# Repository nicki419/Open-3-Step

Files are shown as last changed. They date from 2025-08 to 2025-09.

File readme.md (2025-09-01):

# Open 3 Step

Open-Source Circuit and code for custom built 120/240V 3-step (or  n-step) light bulb dimmer working by turning off/on the light switch  quickly to switch between brightness levels. Also provides  memory-functionality to non-memory 3-step bulbs.
Please take the time to read everything. It would mean a lot to me. Otherwise, just move on to docs/howto.md

---

### Background

I want to build a lamp. After making a beautiful frame for it, 3D-designing and printing bulb holders and other components, and buying designer LED bulbs (3 pairs of different bulbs, for a total of 6), I discovered that four of those bulbs were 3-step dimmable, and two were TRIAC dimmable. I therefore set out to make my TRIAC bulbs 3-step dimmable, with a memory function, so they could work with my 3-step bulbs.

I soldered a 5V power supply with some fuses, capacitors and resistors to a 30x70mm prototyping board, did the same for an ATMEGA328P, an EEPROM and some GPIO headers, wrote the arduino sketch (see v0.1 code) and it worked, after lots of debugging. If not for the next thing I discovered, this repository would not exist.

The dimming worked. The memory worked. Then it hit me. All four of my 3-step dimmable bulbs are from the same company, and have the exact same box design, with a myriad of icons on the side showing its features. Only after making v0.1 did I realise that two of the bulbs did NOT have a memory function, and two more did. So I now had four bulbs with memory, and two without. Since I also bought regular AC switch modules next to the RBDimmer module, I decided to make another version that would also control the two 3-step bulbs without memory.

Over the summer, I learned the basics of PCB Design and ordered my boards for the next version. I got some more components to make this project more easily customisable and added potentiometers for more easy brightness control at the three steps, as well as support for the non-memory 3-step bulbs.

### Versions

**0.2**

This version will implement the features described above on a custom PCB. All the components will, however, also fit on a 30x70mm prototyping board, if you really want to go that route.

To not clutter the repo, I will share exported PDFs, gerber files, STLs, etc. only via releases.

Changelog:

- Add Support for non-memory 3-step bulbs through fast switching when the system powers up
- Add analogue input via 100K potentiometers and a button to configure the brightness levels outside of code
- Move from arduino to platformio and add separate debug and release profiles (release will have no LED blinking)
- Create Settings Mode for configuring brightnesses and saving into EEPROM
- Create 3-step calibration mode to find out how long the delay in your bulbs is.

**0.1**

The original version is fully implementable on prototyping boards. This is also where the power supply comes from. I chose not to create schematics for the power supply, but there is documentation on what's required and recommended when creating it. If you only need 3-step dimming with a memory function, you may use the code from both v0.1 and v0.2. They should hopefully be cross-compatible, as the new board only adds things, it doesn't modify any existing pins. Consult the documentation of the v0.2 code once it fully releases on how to do this. During development, you probably want to use the v0.1 code, instead.

Therefore, you can refer to the schematics for v0.2 on how to wire everything. You simply need to leave out the push button, potentiometers, and the additional GPIO pin for the AC switch. You also need to configure the values for your bulb in code. For v0.2, I will place these in a header file, for v0.1, there is an array defined at the top of the code.

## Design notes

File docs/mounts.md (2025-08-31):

### 3D-Printed Mounts

I have included my 3D-printed mounts for all the PCBs in use in this repository. 
They include screwholes at the bottom to screw them into wood. 
I have done this because I will carve out parts of the wooden frame of my lamp to mount these.

They have been created in OpenSCAD, so it should be relatively easy to modify. 
If there's a release, you will find STL files in it. If not, just download openscad, open the files
and press F6 to render and F7 to export.

Files starting with an underscore are modules. They are only used in other files, you do not need to open these.

The RBDimmer module comes with an M2 version as well. That file also includes the washers needed to mount it with M2 screws.

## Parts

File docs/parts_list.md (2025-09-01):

# Parts List

This file covers the parts required for both v0.1, v0.2, and the power supply.

An asterisk denotes parts optional, but recommended. Links are non-affiliate AliExpress Links. I cannot guarantee that these will remain online, and I will not actively update them.

### General Purpose
These are "universal" parts you will need either way, so I will list them here. I will not add links because they are easy enough to find
- Solid Core Wire (both for soldering and connecting between terminal connectors
- GPIO Jumper Cables. Recommend you get Male to Male, Male to Female, and Female to Female. 
- Solder (duh)
- Flux/Rosin
- "Wire solder holder" (for lack of better description) Highly recommended because you'll likely solder gpio cables to thicker ones
  https://www.aliexpress.com/item/1005009535618361.html
- Stranded Wire rated for 240V 
- M2 and M3 Brass Screw inserts (M3 only needed for the RBDimmer. You can use M2 as well and use 3D-printed washers)

### V0.2 PCB
You have many options of ordering your PCB. I went with PCBWay because they offer IOSS (EU Vat prepaid) shipping methods, which is essential for delivery to where I live. Should you also choose PCBWay and have not ordered with them before, I would appreciate if you signed up using my referral link. You will get \$5 off on your first order, I get \$10 in coupons. That's all there's to it. [Click here <3](https://pcbway.com/g/Qr5ZNd)

### Power Supply

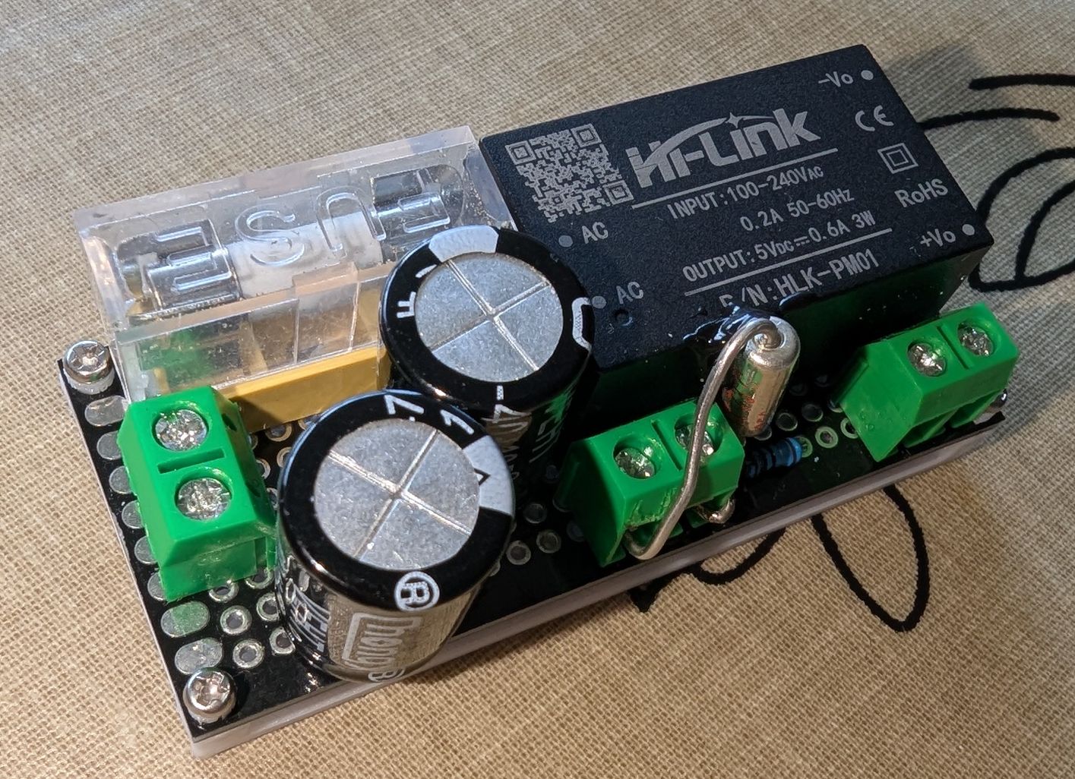
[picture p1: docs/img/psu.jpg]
Power Supply Unit


| Qty | Part | Link |
|---|---|---|
| 1 | 30x70mm Prototyping Board | https://www.aliexpress.com/item/1005009550650037.html |
| 1 | HLK-PM01 Power Supply Unit | https://www.aliexpress.com/item/1005007038304937.html |
| 2 (3*)<sup>1</sup> | KF301 2 Pin Terminal Connector | https://www.aliexpress.com/item/1005006642865467.html |
| 2 | 4700µF 10V Electrolytic Capacitors | https://www.aliexpress.com/item/1005008896677668.html |
| 1* | 5x20mm 250V 0.5A Slow-Blow Fuse | https://www.aliexpress.com/item/32871909497.html |
| 1* | 5x20mm Fuse Holder | https://www.aliexpress.com/item/1005005645173789.html |
| 1*<sup>1</sup> | 73° Thermal Fuse | https://www.aliexpress.com/item/1940867762.html |
| 1 | 10Ω Resistor | https://www.aliexpress.com/item/1005009329218922.html |

**Notes**

1. A third terminal connector I have used to mount the Thermal fuse. This is not good practice and you should probably use a connector made for these fuses.
   Do not make the same mistake as I and try to solder them. Turns out thermal fuses blow when they get hot. ;)

**Instructions**

- Fuses are in Series with the live line of your input. Their order should not matter, as the thermal fuse can handle 10A.
- Capacitors are in parallel with the HLK-PM01 output lines.
- The Resistor is in Series with the HLK-PM01's VCC output line before the caps. (I did it after, which is wrong. This resistor prevents current surge when charging capacitors, especially when adding more later)
- Use silicon rubber thermal glue to attach the thermal fuse to the HLK-PM01.

### v0.1
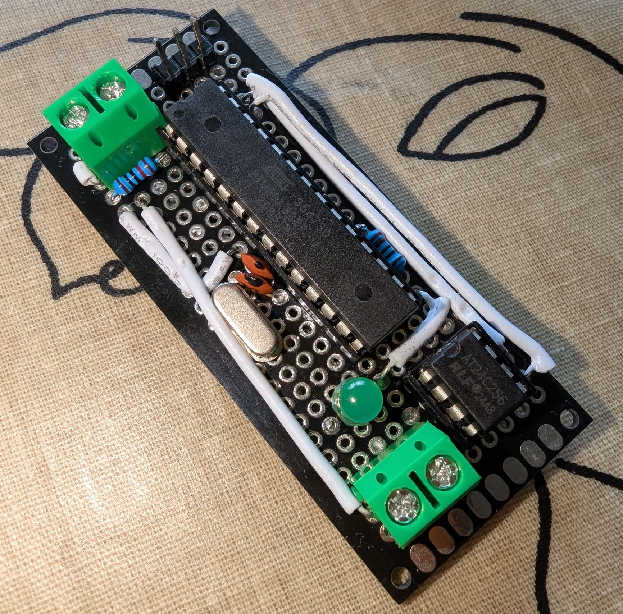
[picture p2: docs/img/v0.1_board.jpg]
V0.1 Board


| Qty | Part | Link |
|---|---|---|
| 1 | 30x70mm Prototyping Board | https://www.aliexpress.com/item/1005009550650037.html |
| 1 (2*)<sup>1</sup> | KF301 2 Pin Terminal Connector | https://www.aliexpress.com/item/1005006642865467.html |
| 1<sup>2</sup> | 16 MHz HC-49S Crystal Oscillator | https://www.aliexpress.com/item/1005005293770220.html |
| 2<sup>2</sup> | 30pF Ceramic Capacitor | https://www.aliexpress.com/item/1005007792464333.html |
| 1 | 5V LED | https://www.aliexpress.com/item/1005009402134026.html |
| 1 | 10KΩ Resistor | https://www.aliexpress.com/item/1005009329218922.html |
| 1 | 220Ω Resistor | https://www.aliexpress.com/item/1005009329218922.html |
| 2<sup>3</sup> | 4.7KΩ Resistor | https://www.aliexpress.com/item/1005009329218922.html |
| 1 | 28 Pin Narrow DIP Socket | https://www.aliexpress.com/item/1005006256010892.html |
| 1 | 8 Pin Narrow DIP Socket | https://www.aliexpress.com/item/1005006256010892.html |
| 1 | ATMEGA328P DIP | https://www.aliexpress.com/item/1005008144708950.html |
| 1 | AT24C256 DIP | https://www.aliexpress.com/item/1005006779000585.html |
| 1<sup>4</sup> | 1x3 pin Male GPIO Headers | https://www.aliexpress.com/item/1005003323489438.html |

**Notes**
1. You only need one for input. But I recommend one at the other side of the board for output to the components that have their own PCB.
2. I recommend you find a listing that specifies the load capacitance, like the one I linked. You can then calculate the exact capacitor values needed for your load capacitors.
   Formula: C = 2 × (CL - Cstray) where CL is the load capacitance, and Cstray is the stray capacitance (typically 5pF)
3. My original v0.1 board did not have these, and it worked, but that turned out to be dumb luck. I highly recommend you add them.
   Needed for I2C communication between the ATMEGA328P and the AT24C256.
4. Buy any size, unlike the female ones, these are easy to cut.

### v0.2

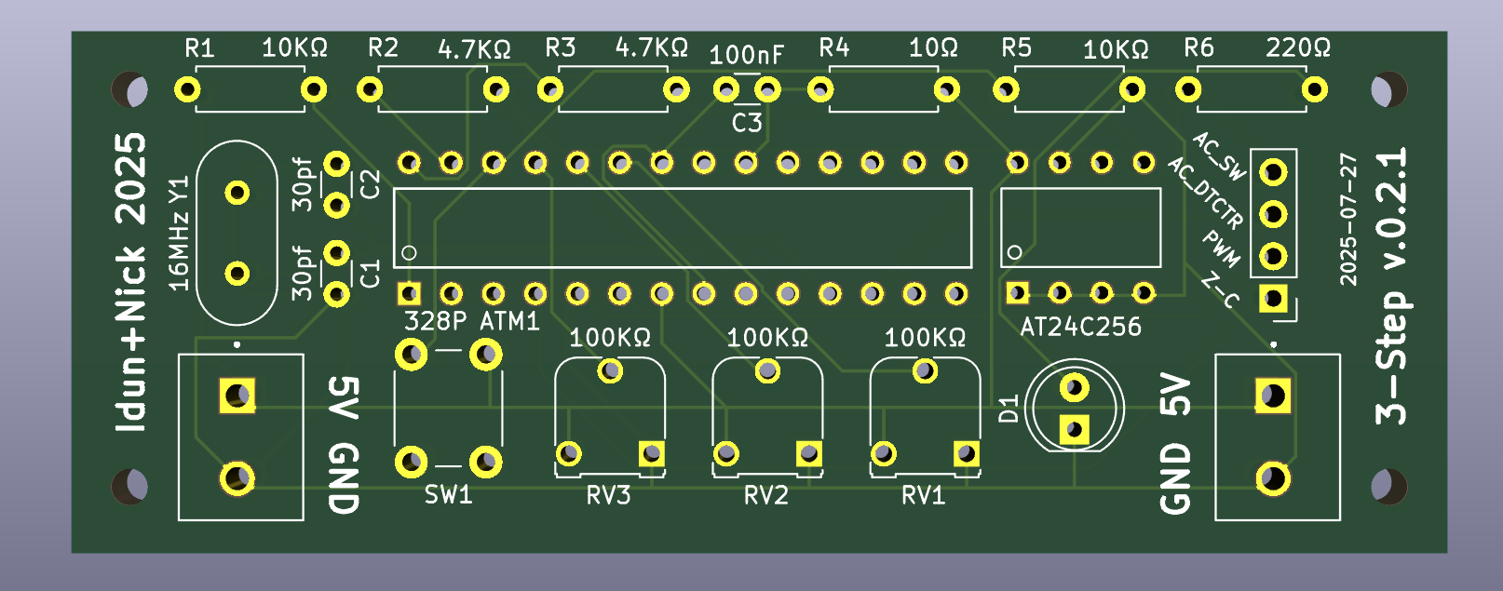
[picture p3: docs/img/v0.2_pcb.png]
V0.2 PCB


| Qty | Part | Link |
|---|---|---|
| 1 | PCB from Repo | [My PCBWay Referral Link](https://pcbway.com/g/Qr5ZNd) |
| 2 | KF301 2 Pin Terminal Connector | https://www.aliexpress.com/item/1005006642865467.html  |
| 1<sup>1</sup> | 16 MHz HC-49S Crystal Oscillator | https://www.aliexpress.com/item/1005005293770220.html  |
| 2<sup>1</sup> | 30pF Ceramic Capacitor | https://www.aliexpress.com/item/1005007792464333.html  |
| 1 | 100nF Ceramic Capacitor | https://www.aliexpress.com/item/1005007792464333.html  |
| 1 | 5V LED | https://www.aliexpress.com/item/1005009402134026.html  |
| 2 | 10KΩ Resistor | https://www.aliexpress.com/item/1005009329218922.html  |
| 1 | 220Ω Resistor | https://www.aliexpress.com/item/1005009329218922.html  |
| 2 | 4.7KΩ Resistor | https://www.aliexpress.com/item/1005009329218922.html  |
| 1 | 10Ω Resistor | https://www.aliexpress.com/item/1005009329218922.html  |
| 1 | 28 Pin Narrow DIP Socket | https://www.aliexpress.com/item/1005006256010892.html  |
| 1 | 8 Pin Narrow DIP Socket | https://www.aliexpress.com/item/1005006256010892.html  |
| 1 | ATMEGA328P DIP | https://www.aliexpress.com/item/1005008144708950.html  |
| 1 | AT24C256 DIP | https://www.aliexpress.com/item/1005006779000585.html  |
| 1<sup>2</sup> | 1x4 pin Male GPIO Headers | https://www.aliexpress.com/item/1005003323489438.html  |
| 1 | 6x6mm TS-D001 Tactile Switch | https://www.aliexpress.com/item/1005004159746274.html  |
| 3 | RM065 100KΩ Potentiometers | https://www.aliexpress.com/item/1005003523757457.html  |

**Notes**
1. See v0.1 Note 2
2. See v0.1 Note 4

### Other
These are the standalone PCBs. Including Pictures I took in case the links are down.

**Robotdyn RBDimmer Module** https://www.aliexpress.com/item/1005008561862601.html
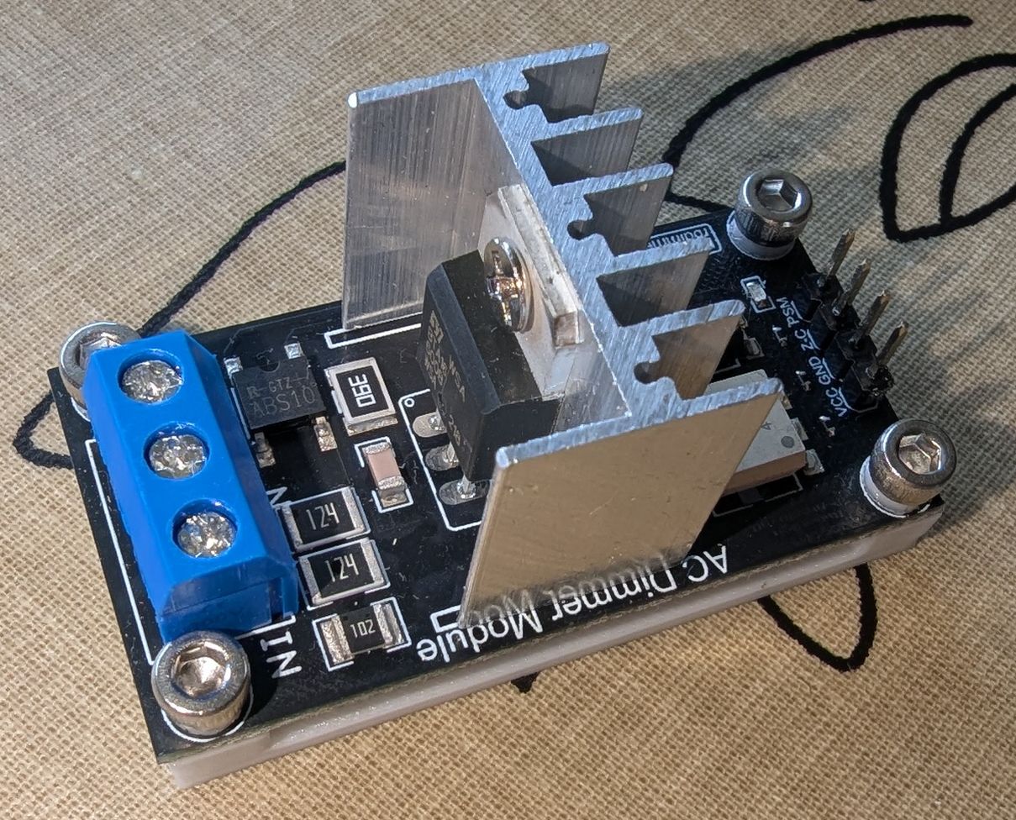
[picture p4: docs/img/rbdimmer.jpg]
RBDimmer Image


**AC Switch (JQC3F-05VDC-C with Control Board (5V)) (v0.2 only, optional)** https://www.aliexpress.com/item/1005004594181635.html

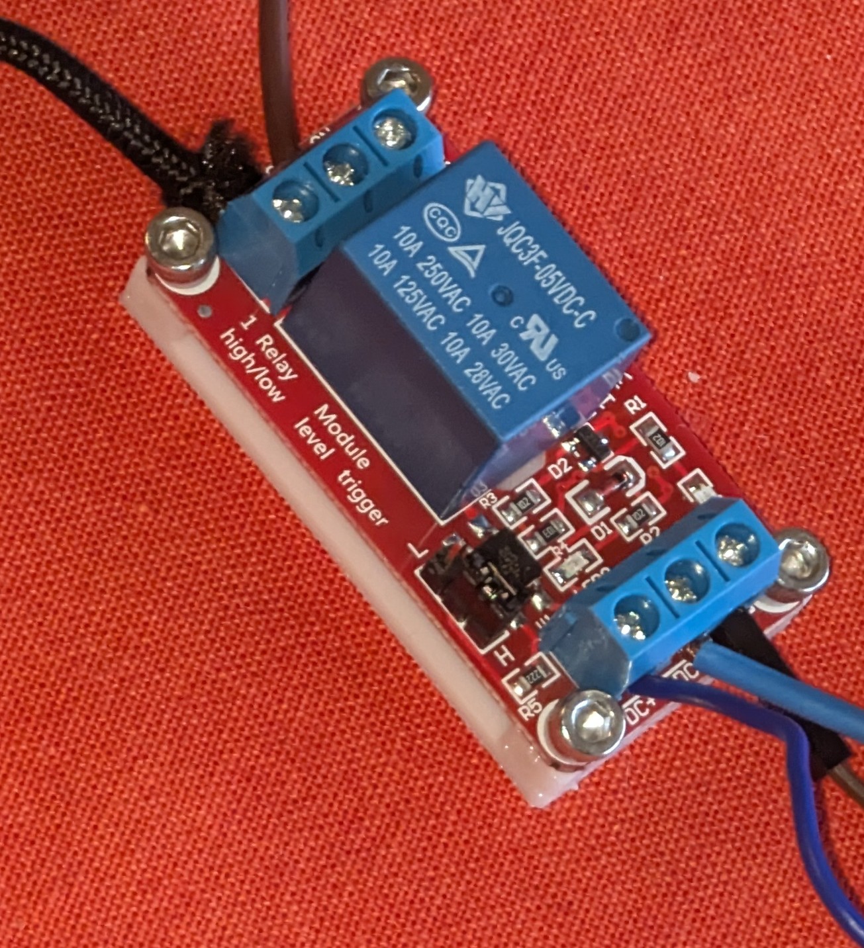
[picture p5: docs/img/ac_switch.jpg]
AC Switch Image


**AC Detector Module 3.3/5V** https://www.aliexpress.com/item/1005005829148627.html
You might ask yourself why we need this. _Can't we just detect the output the the HLK-PM01?_ That Power suppy unit has inbuilt capacitors. It would take a good second after turning off the AC supply for the voltage to drop to 0. This board detects the absence of AC voltage immediately.
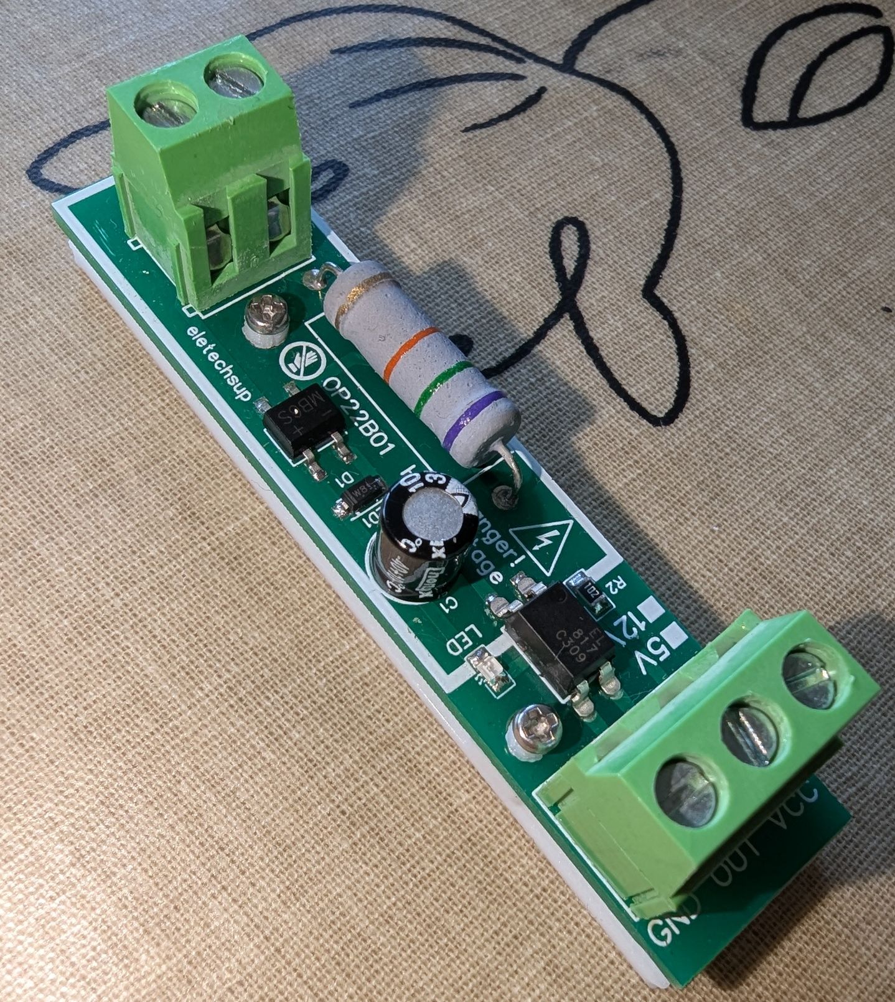
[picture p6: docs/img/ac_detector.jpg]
AC Detector Image


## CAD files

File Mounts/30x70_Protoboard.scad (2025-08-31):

$fn = $preview ? 0 : 100;

include <_modules.scad>;
include <_generic_board.scad>;

length = 70;
width = 30;
height = 2;

mounting_hole_length = 4;
mounting_hole_width = 4;
mounting_hole_height = 4;

screw_hole_x = 15;
screw_hole_y = 15;

difference()
{
    generic_board(length, width, height, mounting_hole_length, mounting_hole_width, mounting_hole_height);
    union()
    {
        translate([screw_hole_x, screw_hole_y, 0])
        wood_hole();
        
        translate([length - screw_hole_x, screw_hole_y, 0])
        wood_hole();
    }
}

translate([(3-3/4), width + 5, 0])
for(i = [0 : 1])
{
    for(j = [0 : 1])
    {
        translate([i*5, j*5, 0]) washer();
        translate([i*5, j*5, 0]) washer();
    }
}

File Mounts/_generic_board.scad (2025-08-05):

module generic_board_m3(
length,
width,
height,
mounting_hole_length,
mounting_hole_width,
mounting_hole_height = 3
)
{
    cube([length, width, height]);

    translate([mounting_hole_length / 2, mounting_hole_width / 2, height])
    mounting_hole_m3(mounting_hole_length, mounting_hole_width, mounting_hole_height);

    translate([mounting_hole_length / 2, width - (mounting_hole_width / 2), height])
    mounting_hole_m3(mounting_hole_length, mounting_hole_width, mounting_hole_height);

    translate([length - (mounting_hole_length / 2), mounting_hole_width / 2, height])
    mounting_hole_m3(mounting_hole_length, mounting_hole_width, mounting_hole_height);

    translate([length - (mounting_hole_length / 2), width - (mounting_hole_width / 2), height])
    mounting_hole_m3(mounting_hole_length, mounting_hole_width, mounting_hole_height);
}

module generic_board(
length,
width,
height,
mounting_hole_length,
mounting_hole_width,
mounting_hole_height = 3
)
{
    cube([length, width, height]);

    translate([mounting_hole_length / 2, mounting_hole_width / 2, height])
    mounting_hole(mounting_hole_length, mounting_hole_width, mounting_hole_height);

    translate([mounting_hole_length / 2, width - (mounting_hole_width / 2), height])
    mounting_hole(mounting_hole_length, mounting_hole_width, mounting_hole_height);

    translate([length - (mounting_hole_length / 2), mounting_hole_width / 2, height])
    mounting_hole(mounting_hole_length, mounting_hole_width, mounting_hole_height);

    translate([length - (mounting_hole_length / 2), width - (mounting_hole_width / 2), height])
    mounting_hole(mounting_hole_length, mounting_hole_width, mounting_hole_height);
}

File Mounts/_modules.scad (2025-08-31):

module mounting_hole(w, l, h=3) 
{
    hole_dia = 3.0;           // slightly undersized for 3.2mm insert
    hole_depth = 2.2;         // slightly deeper than insert
    chamfer_depth = 0.5;      // how deep the chamfer is
    chamfer_top_dia = 3.4;    // wider top to guide insert

    // Create the main hole and chamfer at the top
    difference() 
    {
        translate([-(w/2),-(l/2),0])
        {
            cube([w,l,h]);
        }
        translate([0,0,3+(h-3)+.01]) 
        {
            rotate([180,0,0]) 
            {
                union() {
                    // Main cylindrical hole
                    cylinder(d = hole_dia, h = hole_depth, $fn = 64);

                    // Top chamfered cone
                    cylinder(d1 = chamfer_top_dia, d2 = hole_dia, h = chamfer_depth, $fn = 64);
                }
            }
        }
    }
}

module mounting_hole_m3(w, l, h=3) 
{
    hole_dia = 4.2;           // slightly undersized for 3.2mm insert
    hole_depth = 3;         // slightly deeper than insert
    chamfer_depth = 0.5;      // how deep the chamfer is
    chamfer_top_dia = 4.8;    // wider top to guide insert

    // Create the main hole and chamfer at the top
    difference() 
    {
        translate([-(w/2),-(l/2),0])
        {
            cube([w,l,h]);
        }
        translate([0,0,3+(h-3)+.01]) 
        {
            rotate([180,0,0]) 
            {
                union() {
                    // Main cylindrical hole
                    cylinder(d = hole_dia, h = hole_depth, $fn = 64);

                    // Top chamfered cone
                    cylinder(d1 = chamfer_top_dia, d2 = hole_dia, h = chamfer_depth, $fn = 64);
                }
            }
        }
    }
}

module wood_hole()
{
    hole_dia = 3;
    head_dia = 6;
    hole_depth = 3;
    
    translate([0,0,2.01]) 
    {
        rotate([180,0,0]) 
        union() {
            // Main cylindrical hole
            cylinder(d = hole_dia, h = hole_depth, $fn = 64);

            // Top chamfered cone
            cylinder(d1 = head_dia, d2 = hole_dia, h = 1.25, $fn = 64);
        }
    }
}

module washer(size = 2)
{
    difference()
    {
        cylinder(r=size-size/4, h=1.5);
        cylinder(r=size/2, h=1.5);
    }
}

module washer_m2_to_m3()
{
    difference()
    {
        cylinder(r=3-3/4, h=1.5);
        cylinder(r=1, h=1.5);
    }
}

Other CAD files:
Mounts/AC_Detector.scad
Mounts/AC_Dimmer.scad
Mounts/AC_Dimmer_M2.scad
Mounts/AC_Switch.scad
Mounts/AC_Switch_M2.scad
Mounts/Main_PCB.scad

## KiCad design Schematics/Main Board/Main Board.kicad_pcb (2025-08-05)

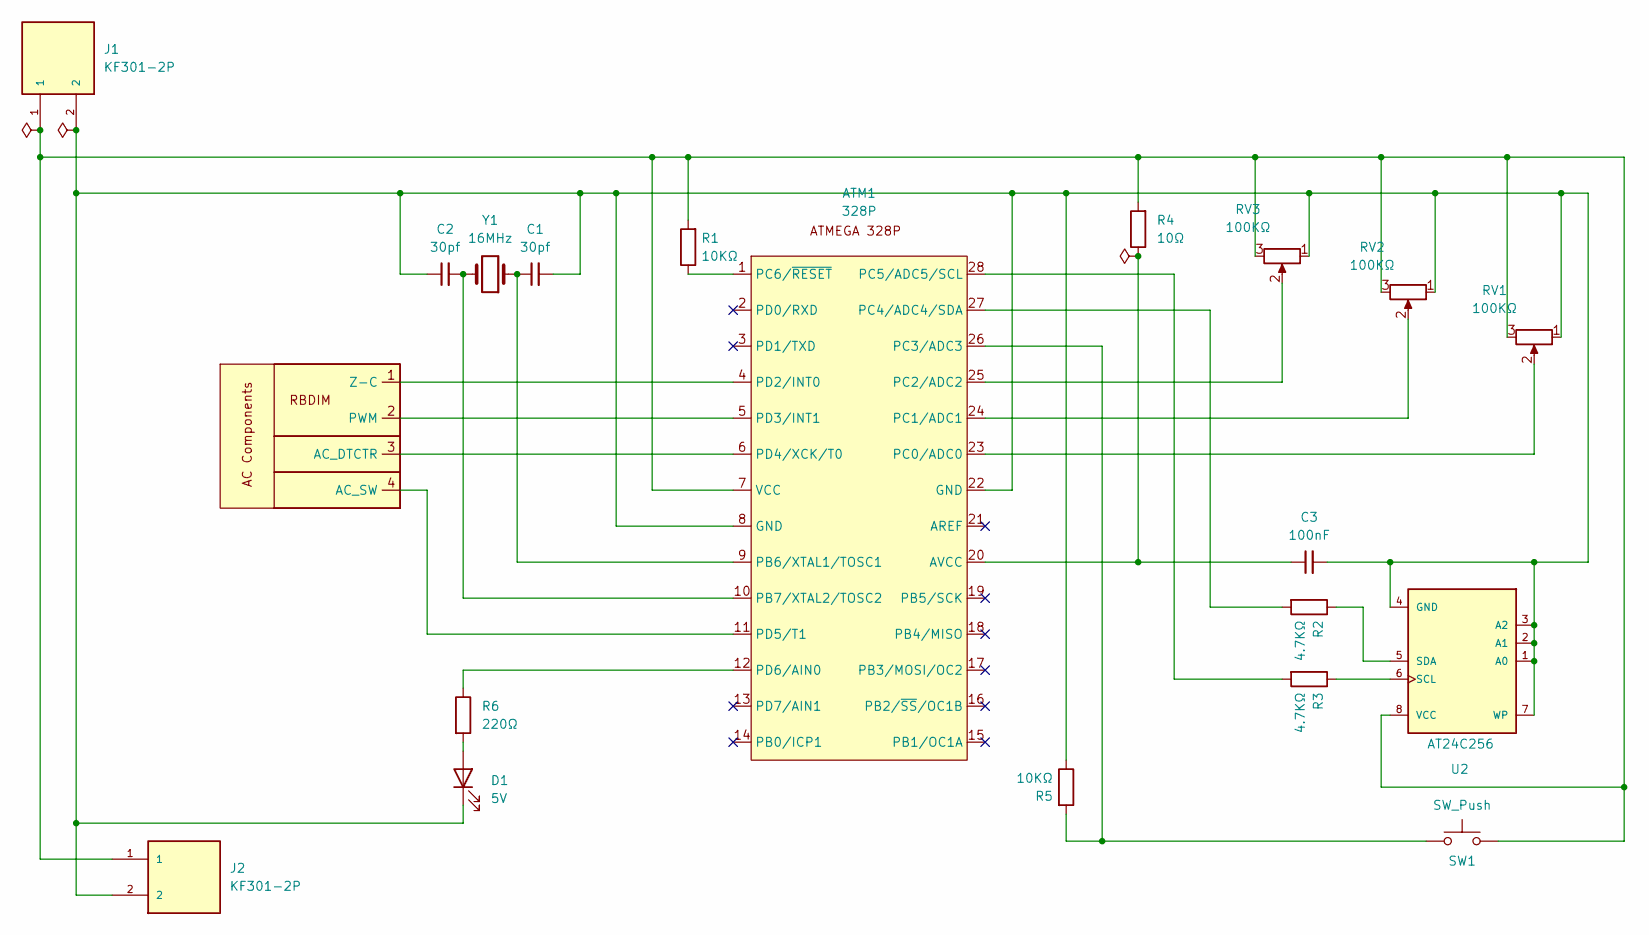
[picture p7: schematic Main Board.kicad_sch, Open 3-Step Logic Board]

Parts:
ATM1: 328P; DIP794W46P254L2967H457Q28B
C1, C2: 30pf; C_Disc_D3.0mm_W1.6mm_P2.50mm
C3: 100nF; C_Disc_D3.0mm_W1.6mm_P2.50mm
D1: 5V; LED_D5.0mm
J1, J2: KF301-2P; HANDSON_KF301-2P; PARTREV NA
R1, R5: 10KΩ; R_Axial_DIN0207_L6.3mm_D2.5mm_P7.62mm_Horizontal
R2, R3: 4.7KΩ; R_Axial_DIN0207_L6.3mm_D2.5mm_P7.62mm_Horizontal
R4: 10Ω; R_Axial_DIN0207_L6.3mm_D2.5mm_P7.62mm_Horizontal
R6: 220Ω; R_Axial_DIN0207_L6.3mm_D2.5mm_P7.62mm_Horizontal
RV1, RV2, RV3: 100KΩ; Potentiometer_Runtron_RM-065_Vertical
SW1: SW_Push; SW_PUSH_6mm_H5mm
U1: PinHeader_1x04_P2.54mm_Vertical
U2: AT24C256; DIP787W46P254L927H533Q8
Y1: 16MHz; Crystal_HC49-U_Vertical

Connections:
unnamed: ATM1.20 (AVCC), C3.1, R4.1
unnamed: ATM1.9 (PB6/XTAL1/TOSC1), C1.1, Y1.1
unnamed: ATM1.10 (PB7/XTAL2/TOSC2), C2.2, Y1.2
unnamed: ATM1.23 (PC0/ADC0), RV1.2
unnamed: ATM1.24 (PC1/ADC1), RV2.2
unnamed: ATM1.25 (PC2/ADC2), RV3.2
unnamed: ATM1.26 (PC3/ADC3), R5.2, SW1.1
unnamed: ATM1.27 (PC4/ADC4/SDA), R2.2
unnamed: ATM1.28 (PC5/ADC5/SCL), R3.2
unnamed: ATM1.1 (PC6/~RESET), R1.1
unnamed: ATM1.4 (PD2/INT0), U1.1 (Z-C)
unnamed: ATM1.5 (PD3/INT1), U1.2 (PWM)
unnamed: ATM1.6 (PD4/XCK/T0), U1.3 (AC_DTCTR)
unnamed: ATM1.11 (PD5/T1), U1.4 (AC_SW)
unnamed: ATM1.12 (PD6/AIN0), R6.1
unnamed: ATM1.7 (VCC), J1.1, J2.1, R1.2, R4.2, RV1.3, RV2.3, RV3.3, SW1.2, U2.8 (VCC)
unnamed: D1.2 (A), R6.2
unnamed: ATM1.8 (GND), ATM1.22 (GND), C1.2, C2.1, C3.2, D1.1 (K), J1.2, J2.2, R5.1, RV1.1, RV2.1, RV3.1, U2.1 (A0), U2.2 (A1), U2.3 (A2), U2.4 (GND), U2.7 (WP)
unnamed: R3.1, U2.6 (SCL)
unnamed: R2.1, U2.5 (SDA)

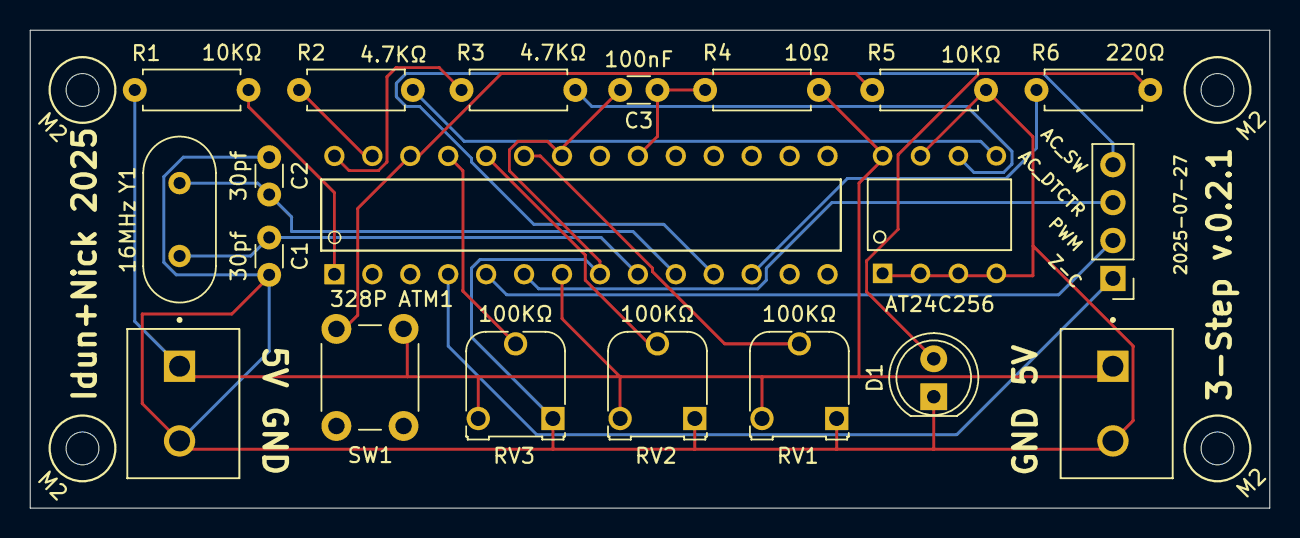
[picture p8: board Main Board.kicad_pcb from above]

Board: 2 copper layers, 83.0 x 32.0 mm, 20 parts (0 on the bottom side), 20 nets.

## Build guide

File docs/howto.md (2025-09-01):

# How To Install and Setup the Dimmer

1. Download the latest release. It contains STL files for mounts, schematics pdf and gerber files for the PCB, and compiled debug and release firmware for delays of 100ms to 5000ms (explained later)
2. Read through mounts.md and parts_list.md. Order the PCB if you don't want to solder on a protoboard (highly recommended)
3. Solder all components, prepare the boards, wire everything up.
4. Load the debug 5000ms firmware onto your 328P, and "boot" the system.
5. The lamp will either be on full brightness, or off. This is normal.

## Setting up the brightness levels

First things first - you need to decide in what order you want to dim. It can either be HIGH - MEDIUM - LOW or LOW - MEDIUM - HIGH. If you use this system, like me, with another 3-step dimmable lamp, whether that has a memory or not, you need to use the order it uses.

To enter settings mode, double click the button. Your lamp will now assume the brightness the first potentiometer is set to. You can turn the potentiometer, then click the button once. That will show you the new brightness, and also save it to the EEPROM. When setting the lowest brightness, some TRIAC dimmable bulbs have a minimum they can handle on boot, which might be higher than the minimum you can set it to. Mine, for instance, when at its absolute lowest can not turn on from a state of prolonged off-time to it's lowest possible brightness, so I had to configure it to be some 10% brighter than it's theoretical lowest.

Double tap again to exit settings mode. The step you were currently on is the step that will be used. Hence, the settings mode also serves to toggle through the three steps, to sync it up with your 3-step bulbs with their own memory.

## Measuring the delay of your 3-step bulbs

When using this together with regular 3-step bulbs, you'll want to know their max switching delay. You need to match the firmware you use for that delay, hence the release contains delays from 100ms to 5000ms. When not in settings mode, hold the button to enter the calibration mode.

Two important things to note: While calibrating, do not rest your finger on the button. That might trigger a button hold and leave calibration mode. You will also need your phone to be able to record timelapse at 1/2, ideally 1/4 so you can count easier. When testing with a bulb that does not have its own memory, take not of its default state. You DO NOT want to test when on the state before that, because you would not be able to tell it apart.
For example, my bulb defaults to HIGH. I therefore made sure when testing delays it was on MEDIUM. In case the delay tested does trigger it, it would switch to LOW. In case it did not, it would switch to HIGH. That's how I knew I'd foudn my delay. In my bulb, it stopped switching at 4100ms, so my max delay is 4000 ms.

Press the button to toggle at the current delay. It starts at 100ms. The LED will be ON once for every 100ms of delay. Double click the button to increase the delay by 100ms. Do not bother counting. Just keep increasing and testing until you've found the FIRST delay where your lamp no longer switches. Press the button once to repeat that delay, and record the LED with your phone in slow motion. You can then count how often it blinks easily, subtract 100ms, and you'll know your delay.

## The issue of uptime

Capacitors degrade over time. Up to 30% can be expected. I therefore recommend you add, on another protoboard, as many capacitors as necessary according to the following (crude) calculation:

(Your delay + 500ms)*1.3

That will give you your required uptime. Add enough capacitors to reach it. I found each cap adds roughly 500ms, but that'S based on very crude measurements. I consider the system dead as soon as the LED dies, because it's driven by the 328P. I therefore assume as long as the LED is on, the system is live.

Test on a breadboard how many caps you need, add one for good measure, and you're hopefully good to go.

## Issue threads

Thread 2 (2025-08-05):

M3 Washer with M2 Hole for RBDimmer

nicki419, 2025-08-05:
Some People might not want to buy two separate sizes of brass inserts and screws.

- Create a washer covering the M3 hole that will allow users to use M2 screws and brass inserts for the RBDimmer

Closed 2025-08-05.

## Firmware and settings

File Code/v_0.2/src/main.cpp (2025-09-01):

#include <RBDdimmer.h>
#include <Wire.h>
#include <at24c256.h>
#include <Arduino.h>
#include <IO_Pins.h>
#include <brightness_controller.h>
#include <Storage_Addresses.h>
#include <OneButtonTiny.h>

#include "ac_switch_controller.h"
#include "settings_controller.h"
#include "delay.h"

#define AC_SW_DELAY 75

constexpr int brightnessLevels[3] = {30, 60, 100}; // brightness % levels

dimmerLamp dimmer(DIMMER_PIN);
AT24C256* eeprom = nullptr;
BrightnessController* brightnessController = nullptr;
SettingsController* settingsController = nullptr;
ACSwitchController* acSwitchController = nullptr;
OneButtonTiny* button = nullptr;

unsigned long mainsLostTime = 0;
bool mainsPresent = true;
unsigned long lastBlinkTime = 0;
bool ledOn = false;
bool inSettingsLoop = false;
bool inACSwitchLoop = false;

void loadBrightness() {
  const int currentBrightnessIndex = brightnessController->readWithRetry(BRIGHTNESS_INDEX_ADDR, 2);
  brightnessController->setCurrentBrightnessIndex(currentBrightnessIndex);
}

void handleClick() {

}

void handleHold() {

}

void setup() {
  pinMode(MAINS_DETECT_PIN, INPUT);
  pinMode(STATUS_LED_PIN, OUTPUT);
  pinMode(BUTTON_PIN, INPUT);
  pinMode(POT1_PIN, INPUT);
  pinMode(POT2_PIN, INPUT);
  pinMode(POT3_PIN, INPUT);
  pinMode(AC_SW_PIN, OUTPUT);

  Wire.begin();
  dimmer.begin(NORMAL_MODE, ON);
  eeprom = new AT24C256(0x50, Wire);
  brightnessController = new BrightnessController(&dimmer, eeprom);
  button = new OneButtonTiny(
        BUTTON_PIN,
        false,
        false
    );
  settingsController = new SettingsController(&dimmer, eeprom, brightnessController, button);
  acSwitchController = new ACSwitchController(&dimmer, eeprom, brightnessController, button);

  loadBrightness();
  brightnessController->applyBrightness();
  acSwitchController->handleACSwitch(AC_SW_DELAY);

#ifdef DEBUG
  digitalWrite(STATUS_LED_PIN, HIGH);
  delay(50);
  digitalWrite(STATUS_LED_PIN, LOW);
#endif

  button->attachClick([]() {
    if (!inSettingsLoop && !inACSwitchLoop) {
      handleClick();
    }
    else if (inSettingsLoop) {
      settingsController->handle_button_click(brightnessController->getCurrentBrightnessIndex());
    }
    else if (inACSwitchLoop) {
      acSwitchController->handle_button_click();
    }
  });

  button->attachDoubleClick([]() {
    digitalWrite(STATUS_LED_PIN, HIGH);
    delay(100);
    digitalWrite(STATUS_LED_PIN, LOW);
    delay(100);

    if (!inACSwitchLoop) {
      inSettingsLoop = !inSettingsLoop;
      if (inSettingsLoop) {
        brightnessController->setCurrentBrightnessIndex(0);
        settingsController->handle_button_click(brightnessController->getCurrentBrightnessIndex());
      }
    }
    else {
      acSwitchController->handle_button_double_click();
    }
  });

  button->attachLongPressStart([]() {
    if (!inSettingsLoop) {
      inACSwitchLoop = !inACSwitchLoop;
      if (inACSwitchLoop) {
        acSwitchController->currentTestIndex = 1;
        digitalWrite(STATUS_LED_PIN, LOW);
        delay(200);
      }
    }
    else {
      settingsController->handle_button_hold(brightnessController->getCurrentBrightnessIndex());
    }
  });

}

void loop() {
  button->tick();
  const bool currentMains = (digitalRead(MAINS_DETECT_PIN) == LOW);

  if (inSettingsLoop) {
    settingsController->settings_loop(brightnessController->getCurrentBrightnessIndex());
    return;
  }
  if (inACSwitchLoop) {
    return;
  }

  // Mains Power Cycle Check
  if (!mainsPresent && currentMains) {
    if (const unsigned long interruption = millis() - mainsLostTime; interruption <= DELAY) {
      brightnessController->cycleBrightness();
      const int currentBrightnessIndex = brightnessController->getCurrentBrightnessIndex();
      brightnessController->applyBrightness();
      brightnessController->saveBrightnessIndex(currentBrightnessIndex);
    }
    else {
      acSwitchController->handleACSwitch(AC_SW_DELAY);
    }
  }

  if (mainsPresent && !currentMains) {
    mainsLostTime = millis();
  }

  mainsPresent = currentMains;
  brightnessController->handleStatusLED();

  delay(10);
}

void onZeroCross() {
  dimmer.setState(ON);
}

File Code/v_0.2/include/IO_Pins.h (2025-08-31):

//
// Created by nick on 05/08/25.
//

#ifndef IO_PINS_H
#define IO_PINS_H

#define MAINS_DETECT_PIN PD4     // Mains detector output (LOW = mains present)
#define ZERO_CROSS_PIN PD2       // Zero-cross input for dimmer timing
#define DIMMER_PIN PD3           // Dimmer PSM output
#define STATUS_LED_PIN PD6       // External status LED
#define AC_SW_PIN PD5            // AC switch output

#define POT1_PIN A0             // ADC2 (PC2/A2)
#define POT2_PIN A1             // ADC1 (PC1/A1)
#define POT3_PIN A2             // ADC0 (PC0/A0)
#define BUTTON_PIN A3           // ADC3 (PC3/A3) Used as digital input

#endif //IO_PINS_H

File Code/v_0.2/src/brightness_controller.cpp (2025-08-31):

#include <brightness_controller.h>
#include <RBDdimmer.h>
#include <Arduino.h>
#include <at24c256.h>
#include <Storage_Addresses.h>

#ifdef DEBUG
#include <IO_Pins.h>
#endif

BrightnessController::BrightnessController(dimmerLamp* dimmer, AT24C256* eeprom) : dimmer(dimmer), eeprom(eeprom) {

}

bool BrightnessController::writeAndVerify(const byte address, const byte data) const {
    dimmer->setPower(0);
    dimmer->setState(OFF);
    delay(50);
    for (int attempt = 0; attempt < 3; attempt++) {
        eeprom->write(address, data);
        delay(20);

        if (const byte readBack = eeprom->read(address); readBack == data) {
            dimmer->setState(ON);
            applyBrightness();
            return true;
        }
    }

    dimmer->setState(ON);
    applyBrightness();
    return false;
}

byte BrightnessController::readWithRetry(const byte address, const byte defaultValue) const {
    for (int attempt = 0; attempt < 3; attempt++) {
        dimmer->setPower(0);
        dimmer->setState(OFF);
        delayMicroseconds(100);

        if (const byte value = eeprom->read(address); value < 3) {
            dimmer->setState(ON);
            return value;
        }
    }

    dimmer->setState(ON);
    return defaultValue;
}

byte BrightnessController::readBrightnessWithRetry(const byte address, const byte defaultValue) const {
    for (int attempt = 0; attempt < 3; attempt++) {
        dimmer->setPower(0);
        dimmer->setState(OFF);
        delayMicroseconds(100);

        if (const byte value = eeprom->read(address); value >= 1 && value <= 100) {
            dimmer->setState(ON);
            return value;
        }
    }
    dimmer->setState(ON);
    return defaultValue;
}


void BrightnessController::saveBrightnessIndex(const int currentBrightnessIndex) const {
    if (!writeAndVerify(BRIGHTNESS_INDEX_ADDR, currentBrightnessIndex)) {
        // Write failed - indicate error by rapid LED flashing
#ifdef DEBUG
        for (int i = 0; i < 5; i++) {
            digitalWrite(STATUS_LED_PIN, HIGH);
            delay(50);
            digitalWrite(STATUS_LED_PIN, LOW);
            delay(50);
        }
#endif
    }
}

void BrightnessController::applyBrightness() const {
    const int address = currentBrightnessIndex == 0
                            ? BRIGHTNESS_VALUE1_ADDR
                            : currentBrightnessIndex == 1
                                  ? BRIGHTNESS_VALUE2_ADDR
                                  : BRIGHTNESS_VALUE3_ADDR;
    const int brightness = readBrightnessWithRetry(address, 0);
    dimmer->setPower(brightness);
}

void BrightnessController::cycleBrightness() {
    currentBrightnessIndex = (currentBrightnessIndex + 1) % 3;
}

void BrightnessController::handleStatusLED() {
#ifdef DEBUG
    const int brightness = brightnessLevels[currentBrightnessIndex];
    const unsigned long now = millis();

    if (brightness <= 30) {
        // Slow blink
        if (now - lastBlinkTime >= 800) {
            ledOn = !ledOn;
            digitalWrite(STATUS_LED_PIN, ledOn ? HIGH : LOW);
            lastBlinkTime = now;
        }
    }
    else if (brightness <= 70) {
        // Medium blink
        if (now - lastBlinkTime >= 300) {
            ledOn = !ledOn;
            digitalWrite(STATUS_LED_PIN, ledOn ? HIGH : LOW);
            lastBlinkTime = now;
        }
    }
    else {
        // Solid ON for highest brightness
        digitalWrite(STATUS_LED_PIN, HIGH);
    }
#endif
}

int BrightnessController::getCurrentBrightness() const {
    return brightnessLevels[currentBrightnessIndex];
}

int BrightnessController::getCurrentBrightnessIndex() const {
    return currentBrightnessIndex;
}

void BrightnessController::setCurrentBrightnessIndex(const int currentBrightnessIndex) {
    this->currentBrightnessIndex = currentBrightnessIndex;
}

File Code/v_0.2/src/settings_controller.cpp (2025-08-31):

//
// Created by nick on 05/08/25.
//

#include <settings_controller.h>
#include <IO_Pins.h>
#include <OneButtonTiny.h>

#include "Storage_Addresses.h"

int readPotAverage(const int pin, const int samples = 5) {
    int total = 0;
    for (int i = 0; i < samples; i++) {
        analogRead(pin);
        delay(5);
        total += analogRead(pin);
        delay(5);
    }
    return total / samples;
}

void SettingsController::setAndSaveBrightness(const int currentBrightnessIndex) const {
    // Read from ADC
    brightness_controller->setCurrentBrightnessIndex(currentBrightnessIndex);
    const int pin = currentBrightnessIndex == 0 ? POT1_PIN : currentBrightnessIndex == 1 ? POT2_PIN : POT3_PIN;
    const int address = currentBrightnessIndex == 0
                            ? BRIGHTNESS_VALUE1_ADDR
                            : currentBrightnessIndex == 1
                                  ? BRIGHTNESS_VALUE2_ADDR
                                  : BRIGHTNESS_VALUE3_ADDR;
    analogRead(pin);
    delay(10);
    const int pot_reading =  static_cast<int>(map(readPotAverage(pin), 0, 1023, 1, 100));

    // Set dimmer and write on EEPROM
    dimmer->setPower(pot_reading);
    if (const bool result = brightness_controller->writeAndVerify(address, pot_reading); !result) {
        for (int i = 0; i < 5; i++) {
            digitalWrite(STATUS_LED_PIN, HIGH);
            delay(50);
            digitalWrite(STATUS_LED_PIN, LOW);
            delay(50);
        }
    }
}

SettingsController::SettingsController(dimmerLamp *dimmer, AT24C256 *eeprom,
                                       BrightnessController *brightness_controller, OneButtonTiny *button):
    dimmer(dimmer),
    eeprom(eeprom),
    brightness_controller(brightness_controller),
    button(button) {
    last_LED_Blink = millis();

}

void SettingsController::settings_loop(const int currentBrightnessIndex) {
    const unsigned long currentTime = millis();
    
    // Check if we should start a new blink sequence
    if (currentTime - last_LED_Blink >= 1000) {
        blink_state = BLINK_START;
        blink_count = 0;
        blink_timer = currentTime;
        last_LED_Blink = currentTime;
    }
    
    // Handle the blinking state machine
    if (blink_state != BLINK_IDLE) {
        switch (blink_state) {
            case BLINK_START:
                if (blink_count <= currentBrightnessIndex) {
                    digitalWrite(STATUS_LED_PIN, HIGH);
                    blink_state = BLINK_ON;
                    blink_timer = currentTime;
                } else {
                    blink_state = BLINK_IDLE;
                }
                break;
                
            case BLINK_ON:
                if (currentTime - blink_timer >= 100) {
                    digitalWrite(STATUS_LED_PIN, LOW);
                    blink_state = BLINK_OFF;
                    blink_timer = currentTime;
                }
                break;
                
            case BLINK_OFF:
                if (currentTime - blink_timer >= 100) {
                    blink_count++;
                    blink_state = BLINK_START;
                    blink_timer = currentTime;
                }
                break;
            default:
                break;
        }
    }
}

void SettingsController::handle_button_click(const int currentBrightnessIndex) const {
    setAndSaveBrightness(currentBrightnessIndex);
}

void SettingsController::handle_button_hold(int currentBrightnessIndex) const {
    currentBrightnessIndex = (currentBrightnessIndex + 1) % 3;
    setAndSaveBrightness(currentBrightnessIndex);
}

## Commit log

2025-08-05 Initial Commit - v0.1 Code - v0.2 Empty PIO Project - Kicad Project for the main logic circuit - OpenSCAD Files for (P)CB mounts
    [30x70_Protoboard.scad, AC_Detector.scad, AC_Dimmer.scad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]
2025-08-05 Remove Gerber Files; Update gitignore
    [Main Board-B_Cu.gbr, Main Board-B_Mask.gbr, Main Board-B_Paste.gbr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]
2025-08-05 documentation (#3)
    * Added readme, parts list, and 3d-print mounts documentation
    * fix gitmodules
2025-08-05 Added M2 version of the AC Dimmer Mount
    [AC_Dimmer_M2.scad]
2025-08-31 Updated AC Switch mount to new component, added washers to each compo… (#6)
    * Updated AC Switch mount to new component, added washers to each component separately
    * Updated image and docs for new relay
    [30x70_Protoboard.scad, AC_Detector.scad, AC_Dimmer.scad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]
2025-09-01 Fix resistor placement in parts list instructions (#13)
